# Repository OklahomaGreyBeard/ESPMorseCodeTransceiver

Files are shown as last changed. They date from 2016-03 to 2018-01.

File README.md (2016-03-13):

# ESPMorseCodeTransceiver
A web enabled internet of things morse code sending key with a receiving speaker using the ESP8266.

See a video about this project here:

<a href="http://www.youtube.com/watch?feature=player_embedded&v=fGk9IvxCnt0
" target="_blank">ESP Morse Code Transceiver Video</a>

I used a J-38 WW2 era telegraph key, which can be purchased rather inexpensively on ebay, and 3d printed a case for the bottom for an ESP8266.  I implemented a websocket interface, web server, and morse code decoder, and encoder / sounder.

The original idea for this project was to simply make an IoT button, but things evolved when the idea for dynamic command structures via Morse code came about. With a bit of code extension, this system can easily be made into an internet of things button for home automation, not unlike the amazon 'dash' button, but with the ability to key in dynamic data.  One example would be outputting a REST or MQTT command such as "L50" to a system like OpenHAB, to turn a light on to a 50% dimmer setting.

It can work as a training device, or with a bit of work, send commands to home automation systems, twitter, etc.

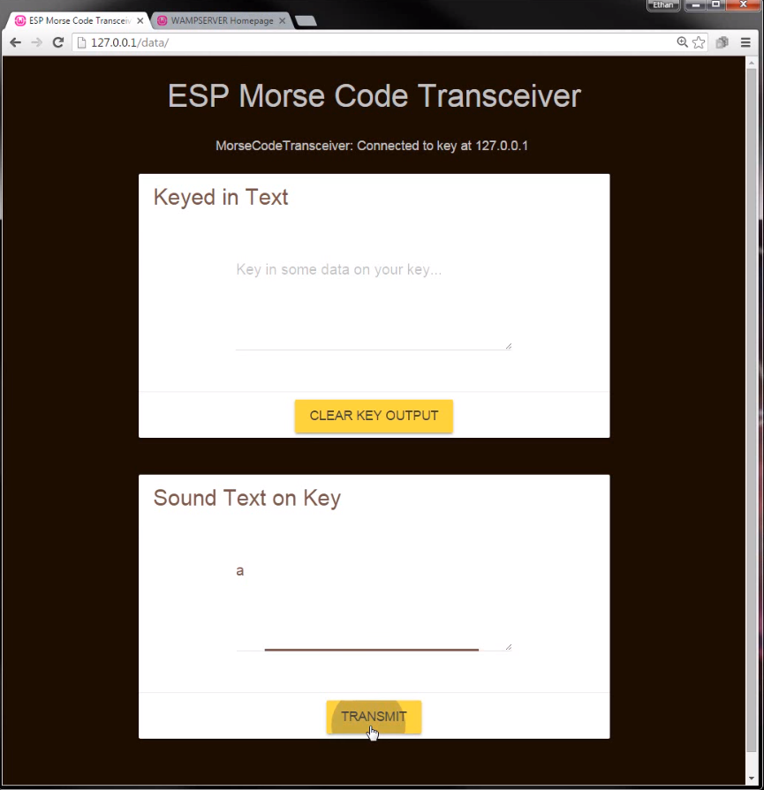
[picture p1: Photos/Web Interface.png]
WebUI

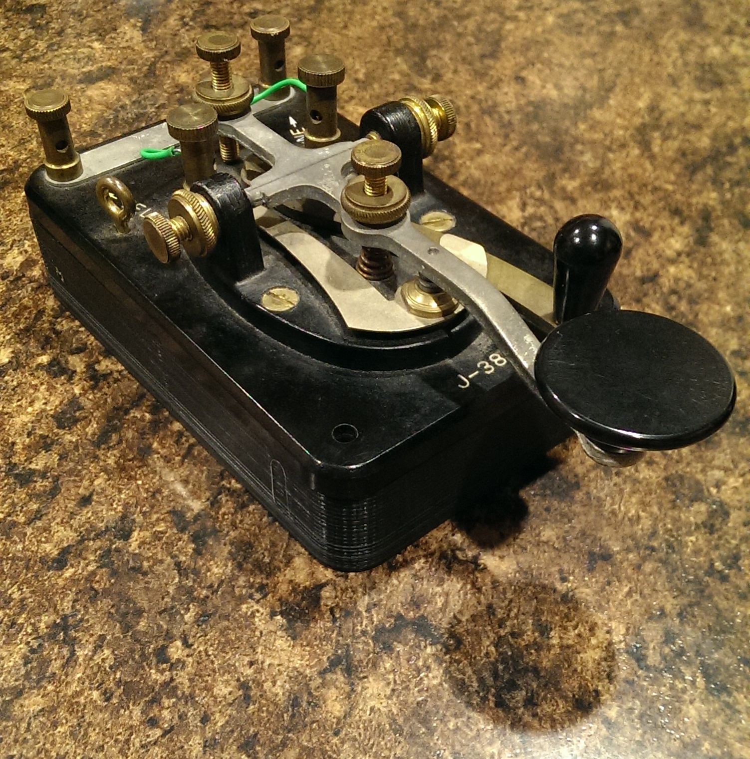
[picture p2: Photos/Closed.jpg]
Closed

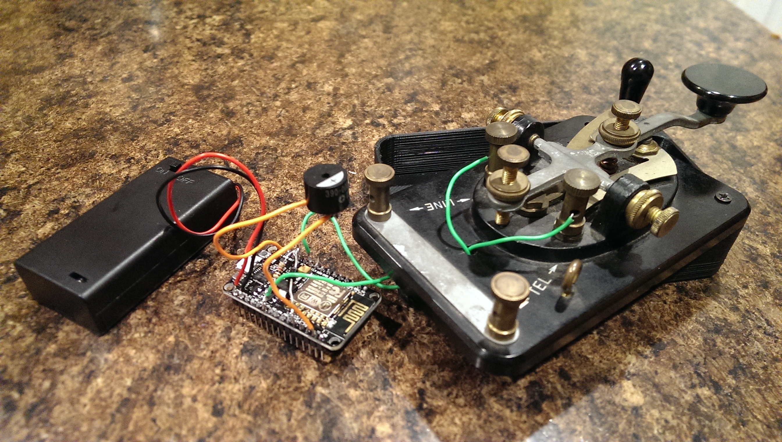
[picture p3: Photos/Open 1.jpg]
Open


Setup Instructions:

Install arduino
get esp arduino with board manager from github link
get arduinoWebSockets-master library
get/install ESP8266fs for the arduino ide.  This lets you send the web content to the eeprom.
Install wifimanager library by tzapu from library manager in arduino ide.
Be sure to restart the arduino IDE

esp will start and bring up an AP, connect to it with password "password"

go to http://esp/, or 192.168.4.1.

Configure wifi.

http://<your esp ip/

To use the key, you'll first need to set the base timing.  Once you hear the "connected" sound, hold the key down for the lenth of a 'dot'.  That will become your base timing, as well as the transmit timing.

You can use the web interface to send ascii text to the receiver, or optionally: http://<esp ip/write?val=SOS to have the ESP sound out or "receive" data.

Here is the electrical schematic you'll need to wire.  It holds the EN / CH_PD pin down when the key is closed so little or no power is used.  Open the key to power up!

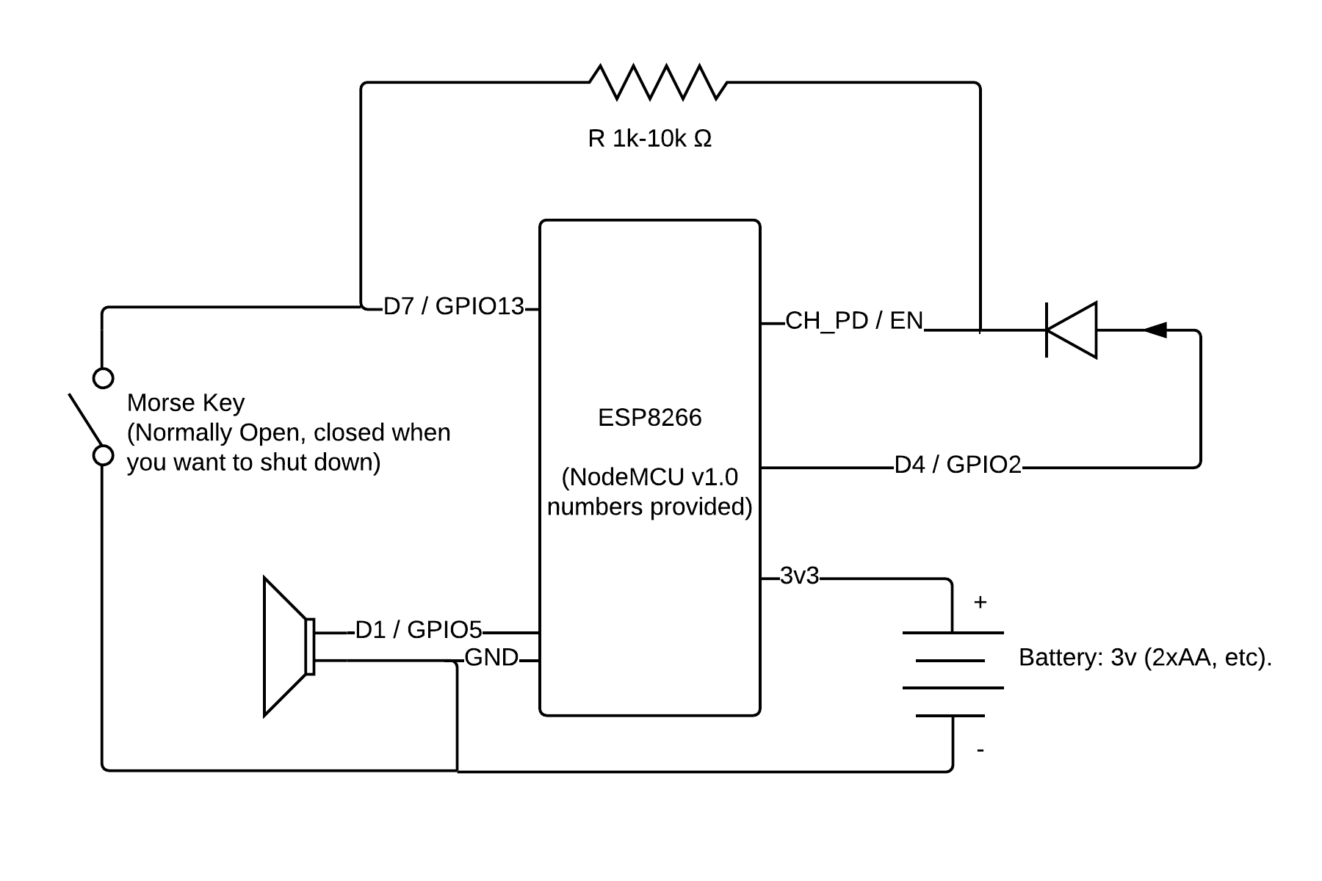
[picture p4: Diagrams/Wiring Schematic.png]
Schematic


Pull requests are welcome, there are lots of "TODO" items to make eveything work better, and some are features I may or may not get around to adding.

If you plan to modify or contribute to the key input sequence, this diagram might be helpful:

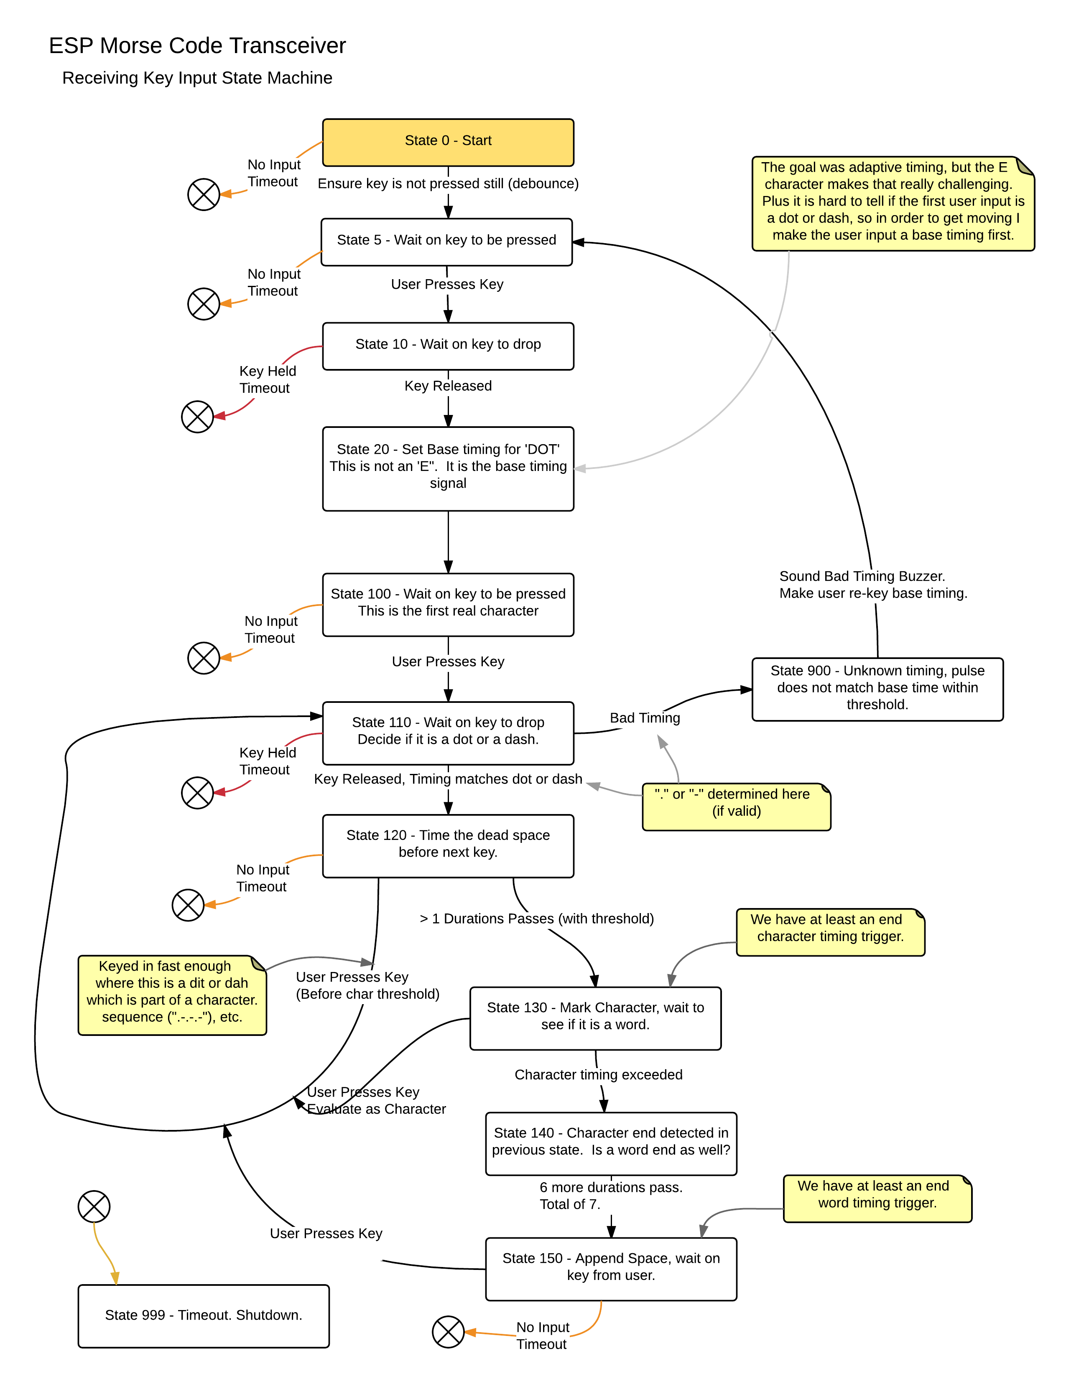
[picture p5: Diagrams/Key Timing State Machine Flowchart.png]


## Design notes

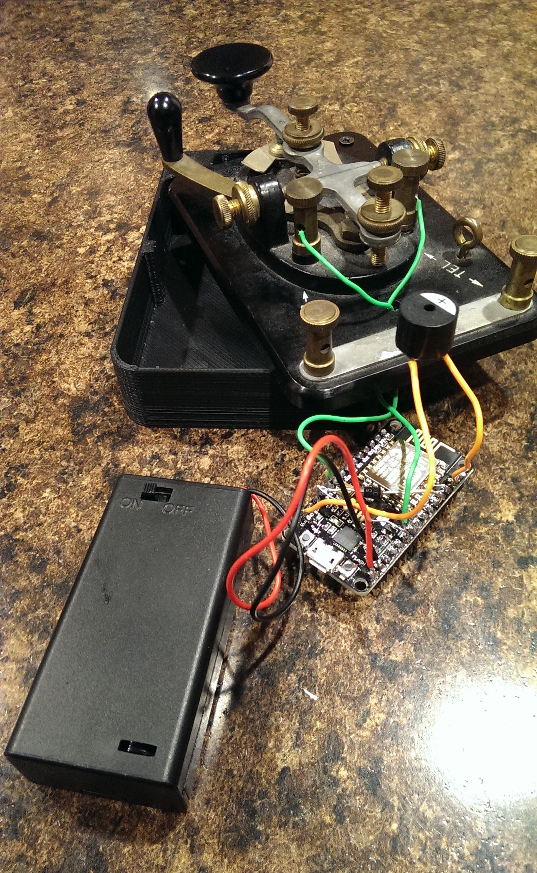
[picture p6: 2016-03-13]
Photos/Open 2.jpg

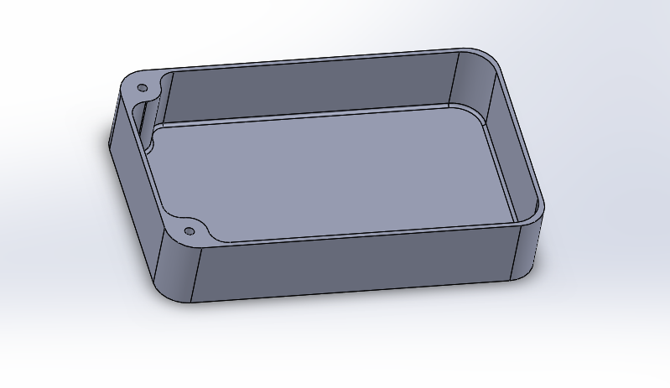
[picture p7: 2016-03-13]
CAD/Case Bottom Screenshot J-38 Key.png

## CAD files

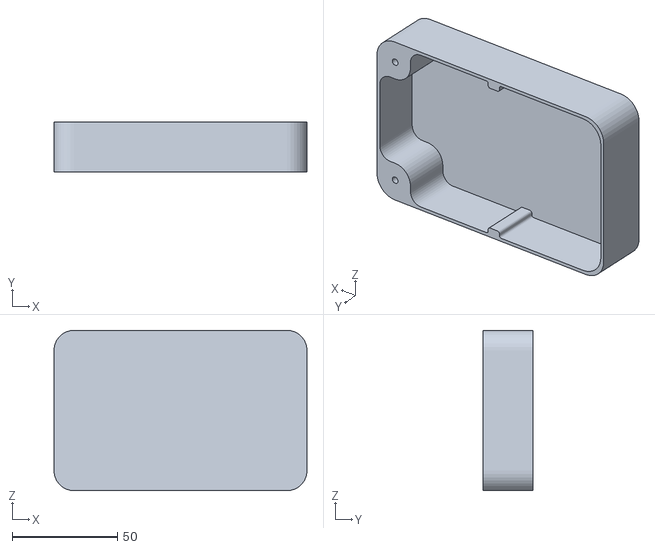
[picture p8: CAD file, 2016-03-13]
CAD/Case Bottom Screenshot J-38 Key.STL
120.4 x 24.0 x 76.3

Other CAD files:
CAD/Case Bottom Screenshot J-38 Key Solidworks 2016.SLDPRT

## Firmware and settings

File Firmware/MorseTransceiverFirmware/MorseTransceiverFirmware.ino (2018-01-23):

#include <WiFiManager.h>


 /*
 * MorseTransceiver.ino
 *
 *  Created on: Mar01 2013
 *
 *  By: evanmj@gmail.com
 *  
 *  Based morse code/timing from: http://morsecode.scphillips.com/morse2.html
 *  
 *  TODO: Consider beeping while button down? Mayb as an option.
 *  TODO: Not all supported characters handled properly.  Need added to array.
 *  TODO: Prosigns not supported, SOS being one of them as 3 chars it no char space.
 *  TODO: full stop (period char) should newline on websocket.
 *  TODO: If any websockets connected, avoid timeout!
 *  TODO: REST output on some signal, maybe full stop, but probably something less used like "!"?
 *  TODO: Handle delete key to clear screen or backspace. "........"
 *  TODO: Different noise if too high or too low
 *  TODO: Shutting lever for a while needs to kill it even when being transmitted to.
 *  
 */

#include <Arduino.h>

#include <ESP8266WiFi.h>
#include <ESP8266WiFiMulti.h>
#include <WebSocketsServer.h>
#include <ESP8266WebServer.h>
#include <ESP8266mDNS.h>
#include <Hash.h>
#include <Timer.h>


#include <FS.h>

#define USE_SERIAL Serial

// Setup automatic magic wifi selection system.
ESP8266WiFiMulti WiFiMulti;

// Instantiate server objects
ESP8266WebServer server(80);
WebSocketsServer webSocket = WebSocketsServer(81);

/* CONSTANTS */


//static unsigned long KEY_DEBOUNCE_TIME = 6000; // Units: microseconds. Per: http://www.qsl.net/sv8gxc/blog/100905-03.jpg, 1.2 sec per pulse = 1 WPM, 140WPM is super fast, so .006 seconds (6ms) seems legit for debounce (max 200WPM detectable).  
static unsigned long KEY_DEBOUNCE_TIME = 9000; // Units: microseconds. Make a bit softer.  A capacitor will probably help but there is not one within reach.
static float PULSE_DURATION_THRESHOLD = 0.50; // How close does a duration need to be to a previous duration to match that it is a dot or a dash? (% of time).  Higher is easier on the user, but don't go over 50% of you'll lose the ability to distingusih a dot from a dash!
static float DASH_TO_DOT_TIME_RATIO = 3.0; // This is standard, the time a dot is is one time unit, one dash is 3 time units.
static float TIME_BETWEEN_CHARS = 3.0; // This is standard, three non transmitting time constant between characters,
static float TIME_BETWEEN_WORDS = 7.0; // This is standard, the non transmitting time constant between words, typically 7 dot time constants.
static float DEFAULT_BASE_TIME_MICROS = 100000; // Default Base time, receive sounds at this rate until user keys in a new rate.  Number in microseconds per 'dot' time constant.
static unsigned long RECIEVE_SOUND_FREQ = 1000; // Frequency to play incoming data (Hz) 600-1000Hz typical.
static unsigned long NO_INPUT_TIMEOUT = 60000; // 30 seconds to shut down with no input.
static unsigned long KEY_HELD_TIMEOUT = 5000; // 5 seconds to shut down with key held down.


/* LOCAL VARIABLES */

int iState; // State machine state.
int iLastState; // Previous State machine state.
bool bFirstScanInState; // True for one time through when state is first entered.
bool bCharEndTimerElapsed; // True when CharEnd timer expires, user lets off for 3 key durations.

bool bWD_Done;  // Watchdog timer elapsed.

// Time keeping of input key pushes
volatile unsigned long iKeyStateChangedTime = 0; // Value in microseconds.
volatile unsigned long iKeyInStateForDeltaTime = 0;  // How long was the key in state for?
bool bKeyPressed; // We will need to keep track of if the button is pressed or not, and the duration.  False = not pressed, True = pressed.
unsigned long iBaseKeyDuration = DEFAULT_BASE_TIME_MICROS; // Scratch space for storing previous key lengths.  Start with a number in case we sound out a message before user inputs one to set base rate.


// Declare timer
Timer Watchdog_tmr;
int Watchdog_tmrEventID;

Timer CharEndTimer;
int CharEnd_tmrEventID;




//In progress character
String DotDashString;  //  dot-dash character array.
char DecodedChar; // ascii char decoded from user input

//In progress String, pre send to REST, etc.  Terminated (eventually) by full stop (period).
String CurrentDecodedString;
char NewestDecodedCharacter;

const char latinAlphabet[30] = { 'A', 'B', 'C', 'D', 'E', 'F', 'G', 'H', 'I', 'J', 'K', 'L', 'M', 'N', 'O', 'P', 'Q', 'R', 'S', 'T', 'U', 'V', 'W', 'X', 'Y', 'Z', '.', ',' };
// NOTE: Does not handle lower case.  Convert all inputs to upper before comparing.

const String morseAlphabet[30] = { ".-", "-...", "-.-.", "-..", ".", "..-.", "--.", "....", "..", ".---", "-.-", ".-..", "--", "-.", "---", ".--.", "--.-", ".-.", "...", "-", "..-", "...-", ".--", "-..-", "-.--", "--..", ".-.-.-", "--..--" };

String DecodedStringToTransmit;  // String in morse to send to the speaker.
String PayloadAsString;  // Uppercase String in morse to send to the speaker.

/* END LOCAL VARIABLES */


void morse_to_sound(String inputstring, unsigned freq);
void string_to_morse(String &dest, String inputstring); 

/* WEB FUNCTIONS */

// This function runs when a new websocket event arrives.
void webSocketEvent(uint8_t num, WStype_t type, uint8_t * payload, size_t length) {

    switch(type) {
        case WStype_DISCONNECTED:
            USE_SERIAL.printf("[%u] Disconnected!\n", num);
            break;
        case WStype_CONNECTED: {
            IPAddress ip = webSocket.remoteIP(num);
            USE_SERIAL.printf("[%u] Connected from %d.%d.%d.%d url: %s\n", num, ip[0], ip[1], ip[2], ip[3], payload);

            // send message to client
            webSocket.sendTXT(num, "Connected! This message is from the ESP");
        }
            break;
        case WStype_TEXT:
        
            USE_SERIAL.printf("[%u] get Text: %s\n", num, payload);
            Serial.println();

            // Javascript prepends a 't' to let us know to transmit.  Maybe S = settings, etc.  
            if(payload[0] == 't') {
                // we got command data that we need to transmit.

                PayloadAsString = (const char *) &payload[1];

                // Make uppercase so string_to_morse likes it.
                PayloadAsString.toUpperCase();

                // Trim leading character, we are done with it ("t" in this case)
                //PayloadAsString.substring(1);

                // Null this so we don't concat like string_to_morse does.
                DecodedStringToTransmit = "";
                
                // Convert it to dots and dashes.
                string_to_morse(DecodedStringToTransmit,PayloadAsString);
                
                
                Serial.println("Sounding morse payload: " + DecodedStringToTransmit);

                morse_to_sound(DecodedStringToTransmit, RECIEVE_SOUND_FREQ);

            }


            break;

         case WStype_BIN:
            USE_SERIAL.printf("[%u] get binary length: %u\n", num, length);
            
            break;
    }
    

}

// Unused, needs implemented instead of other lame 404
/*void handleNotFound(){
  digitalWrite(led, 1);
  String message = "File Not Found\n\n";
  message += "URI: ";
  message += server.uri();
  message += "\nMethod: ";
  message += (server.method() == HTTP_GET)?"GET":"POST";
  message += "\nArguments: ";
  message += server.args();
  message += "\n";
  for (uint8_t i=0; i<server.args(); i++){
    message += " " + server.argName(i) + ": " + server.arg(i) + "\n";
  }
  server.send(404, "text/plain", message);
  digitalWrite(led, 0);
}*/

String getContentType(String filename){
  if(server.hasArg("download")) return "application/octet-stream";
  else if(filename.endsWith(".htm")) return "text/html";
  else if(filename.endsWith(".html")) return "text/html";
  else if(filename.endsWith(".css")) return "text/css";
  else if(filename.endsWith(".js")) return "application/javascript";
  else if(filename.endsWith(".png")) return "image/png";
  else if(filename.endsWith(".gif")) return "image/gif";
  else if(filename.endsWith(".jpg")) return "image/jpeg";
  else if(filename.endsWith(".ico")) return "image/x-icon";
  else if(filename.endsWith(".xml")) return "text/xml";
  else if(filename.endsWith(".pdf")) return "application/x-pdf";
  else if(filename.endsWith(".zip")) return "application/x-zip";
  else if(filename.endsWith(".gz")) return "application/x-gzip";
  return "text/plain";
}

bool handleFileRead(String path){
  USE_SERIAL.println("handleFileRead: " + path);
  if(path.endsWith("/")) path += "index.html";
  String contentType = getContentType(path);
  String pathWithGz = path + ".gz";
  if(SPIFFS.exists(pathWithGz) || SPIFFS.exists(path)){
    if(SPIFFS.exists(pathWithGz))
      path += ".gz";
    File file = SPIFFS.open(path, "r");
    size_t sent = server.streamFile(file, contentType);
    file.close();
    return true;
  }
  else
  {
    USE_SERIAL.println("File does not exist: " + path);
  }
  return false;
}



/* MORSE FUNCTIONS */

// Let the compiler know about our interrupt functions or it will complain about one calling before the other exists, etc.
extern void risingedge();
extern void fallingedge();


// Convert letters in a string to a string of morse code dots and dashes.
void string_to_morse(String &dest, String inputstring) 
{

  for (unsigned i = 0; i<inputstring.length(); ++i)
    {
        for (int counter = 0; counter < 30; counter++)
        {
                if (inputstring.charAt(i) == latinAlphabet[counter])
                {
                    dest += morseAlphabet[counter];
                    //break;  <= force first char, let user decide instead.
                    
                }
        }
    }

}

// Convert a character to a string of morse code dots and dashes.
void char_to_morse(String &dest, char inputstring) 
{
  
      for (int counter = 0; counter < 30; counter++)
        {
                if (inputstring == latinAlphabet[counter])
                {
                    dest = morseAlphabet[counter];
                                       
                }
        }

}

// Convert morese to an ascii character
char morse_to_char(String inputstring) 
{
    for (unsigned i = 0; i<inputstring.length(); ++i)
    {

      for (int counter = 0; counter < 30; counter++)
        {
                if (inputstring == morseAlphabet[counter])
                {
                    return latinAlphabet[counter];
                                       
                }
        }
      
    }


    
      

}

// Dwell one 'between character' length of time.
void dwell_char()
{
  delay(2*iBaseKeyDuration/1000);  // Delay one 'next character', or 'between characters' pause.  This is typically 3 durations, but morse_to_sound appends one duration already.
}

// Sound out a dot-dash string of morse code, i.e. "..---"
void morse_to_sound(String inputstring, unsigned freq)
{

  for (unsigned i = 0; i<inputstring.length(); ++i)
    {

      if (inputstring.charAt(i) == '.') 
      {
        // Sound DOT  
          analogWriteFreq(RECIEVE_SOUND_FREQ);
          analogWrite(D1, 512);
          delay(iBaseKeyDuration/1000);            // on time.  1 duration.
          analogWrite(D1, 0);
          delay(iBaseKeyDuration/1000);            // gap before next pulse. 1 duration.
      }
      else if (inputstring.charAt(i) == '-') 
      {
        // Sound DASH
          analogWriteFreq(RECIEVE_SOUND_FREQ);
          analogWrite(D1, 512);
          delay(3*iBaseKeyDuration/1000);            // on time.  3 durations.
          analogWrite(D1, 0);
          delay(iBaseKeyDuration/1000);            // gap before next pulse. 1 durations.
      }
      else if (inputstring.charAt(i) == ' ') 
      {
        // Sound SPACE (next word)          
          delay(7*iBaseKeyDuration/1000);            // gap before next pulse. 7 durations.
      }     
    }
  
}

/* INTERRUPT KEY IN FUNCTIONS */

void risingedge() {
    // Start with debounce
    if ((micros() - iKeyStateChangedTime) > KEY_DEBOUNCE_TIME)
    {
      iKeyInStateForDeltaTime = micros() - iKeyStateChangedTime;  // NOTE: BUG HERE.  When this rolls over
      iKeyStateChangedTime = micros();  // Mark for next time.
      //Serial.printf("Rising Edge, Key Pressed Going to 0, was on for %d micros", iKeyInStateForDeltaTime);
      //Serial.println();
      attachInterrupt(digitalPinToInterrupt(D7), fallingedge, FALLING);  // Now set to interrupt on falling edge.
      bKeyPressed = 0;
    }
    else
    {
      //Serial.println("Nulled some rising fuzz");
    }

}
 
void fallingedge() {

    // Start with debounce
    if ((micros() - iKeyStateChangedTime) > KEY_DEBOUNCE_TIME)
    {    
      iKeyInStateForDeltaTime = micros() - iKeyStateChangedTime;  // NOTE: BUG HERE.  When this rolls over
      iKeyStateChangedTime = micros();  // Mark for next time.
      //Serial.printf("Falling Edge, Key Pressed Going to 1, was on for %d micros", iKeyInStateForDeltaTime);
      //Serial.println();
      attachInterrupt(digitalPinToInterrupt(D7), risingedge, RISING);  // Now set to interrupt on rising edge.
      bKeyPressed = 1;
      iKeyStateChangedTime = micros();
    }
        else
    {
      //Serial.println("Nulled some falling fuzz");
    }
 
}

void WDTimerElapsed()
{
  Serial.println("WDTimerElapsed() Running.");
  bWD_Done = 1;
}
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
void loop() {

    webSocket.loop();
    server.handleClient();

    // Make sure TCP and stuff has time to run.
    yield();

    

    // Run state machine.
    switch(iState) {

      case 0:  // Initial - Wait on user to press single key to initiate base timing.
     
        // Runs one time on state entry.
        if (bFirstScanInState == 1) 
        {
          DotDashString = ""; // Null dot dash string.
          // Start watchdog timer.
          Watchdog_tmrEventID = Watchdog_tmr.after(KEY_HELD_TIMEOUT, WDTimerElapsed);  // Set Timer
      
        }
      
        // Start
        if (bKeyPressed == 0)
        {
          iState = 5;  
        }
        else
        {
          Serial.println("Key pressed on start, waiting on it to drop before starting.");
          delay(10);
        }

        // Watch for timeout
        if (bWD_Done == 1)
        {
          Serial.println("WD in State" + iState);
          iState = 999;  // Shutdown.
        }

          

      case 5:  // Wait on first key press - This sets base timing for a "dot", and is not an 'E' character!
     
        // Runs one time on state entry.
        if (bFirstScanInState == 1) 
        {
          // Start watchdog timer.
          Watchdog_tmrEventID = Watchdog_tmr.after(NO_INPUT_TIMEOUT, WDTimerElapsed);  // Set Timer      
        }
      
        // User pressed key.  Go!
        if (bKeyPressed == 1)
        {
          iState = 10;  
        }
        
        // Watch for timeout.
        if (bWD_Done == 1)
        {
          Serial.println("WD in State" + iState);
          iState = 999;  // Shutdown.
        }

        break;

      case 10:  // Wait on key to drop for timing initialization sequence.  The amount of time held here is what the user wants to be a "dot".
     
        // Runs one time on state entry.
        if (bFirstScanInState == 1) 
        {
          // Start watchdog timer.
          Watchdog_tmrEventID = Watchdog_tmr.after(KEY_HELD_TIMEOUT, WDTimerElapsed);  // Set Timer
        }

        // Key _just_ released. 
        // Key went off.  We have our timing.
        if (bKeyPressed == 0)
        {
          iState = 20;  
        }

        // Watch for timeout
        if (bWD_Done == 1)
        {
          Serial.println("WD in State" + iState);
          iState = 999;  // Shutdown.
        }

        break;

      case 20: // Key went off, we should have our base timing now for "dot".

        // Store our base timing.
        iBaseKeyDuration = iKeyInStateForDeltaTime;
        
        // Here is where we could send info to connected websockets to let them know what our WPM is.
        // Wikipedia has the milliseconds to WPM formula... TODO.

        delay(1000);  // Delay 1 second, then echo back what they set.

        // Sound buzzer letting user know how long we recieved their button push, and letting them know it is time to key in some dater.
        analogWriteFreq(RECIEVE_SOUND_FREQ);
        analogWrite(D1, 512);
        delay(iBaseKeyDuration/1000);            // on time.  1 duration.
        analogWrite(D1, 0);
          

        iState = 100;

        break;

      case 100:  // Timing decided.  Wait on first key press for first actual character from user.
     
        // Runs one time on state entry.
        if (bFirstScanInState == 1) 
        {
          // Start watchdog timer.
          Watchdog_tmrEventID = Watchdog_tmr.after(NO_INPUT_TIMEOUT, WDTimerElapsed);  // Set Timer
        }
      
        // User pressed key.  Go!
        if (bKeyPressed == 1)
        {
          iState = 110;  
        }
        
        // Watch for timeout.
        if (bWD_Done == 1)
        {
          Serial.println("WD in State" + iState);
          iState = 999;  // Shutdown.
        }

        break;


      case 110:  // Wait on key to drop for reciving dot or dash..  The amount of time held here is what determines a dot or dash.
     
        // Runs one time on state entry.
        if (bFirstScanInState == 1) 
        {
          // Start watchdog timer.
          Watchdog_tmrEventID = Watchdog_tmr.after(KEY_HELD_TIMEOUT, WDTimerElapsed);  // Set Timer
        }

        // Key _just_ released. 
        // Key went off.  We have our dot or dash timing from the user.
        if (bKeyPressed == 0)
        {
          // We have a push and release time now, it is time to determine if the user wanted a dot or a dash.

          // See what sort of pulse we are dealing with.  If we are about 3x, we have a dash after a dot.  
          if ( iKeyInStateForDeltaTime < (iBaseKeyDuration * (1 + PULSE_DURATION_THRESHOLD)) && (iKeyInStateForDeltaTime > (iBaseKeyDuration * (1 - PULSE_DURATION_THRESHOLD))) )  // Are we +/- 50% (depending on constant) from valid timing?
            {
              Serial.println("110: .");
              DotDashString += "."; // Concatenate input we just received.
     
              iState = 120;  
            }
          else if(iKeyInStateForDeltaTime < (iBaseKeyDuration * ((1 + PULSE_DURATION_THRESHOLD) * DASH_TO_DOT_TIME_RATIO)) && (iKeyInStateForDeltaTime > (iBaseKeyDuration * ((1 - PULSE_DURATION_THRESHOLD) * DASH_TO_DOT_TIME_RATIO))) ) // Are we 250%-350%?  That would be a dash.
            {
              Serial.println("110: -");
              DotDashString += "-";
             
              iState = 120;  
            }
          else{
            Serial.printf("Bad Timing: iBaseKeyDuration Was: %d and you entered: %d", iBaseKeyDuration, iKeyInStateForDeltaTime);
            Serial.println();
            iState = 900;  // Bad timing... Buzz, then Make user re-key base timing.
          }

         
        }

        // Watch for timeout
        if (bWD_Done == 1)
        {
          Serial.println("WD in State" + iState);
          iState = 999;  // Shutdown.
        }

        break;

      case 120:  // Time the dead space before the next key.  This accounts for character endings.  
                 // Timing is important, as some characters are long and contain other character's dot dash sequences in them.
     
        // Runs one time on state entry.
        if (bFirstScanInState == 1) 
        {
          // Start watchdog timer.
          Watchdog_tmrEventID = Watchdog_tmr.after(NO_INPUT_TIMEOUT, WDTimerElapsed);  // Set Timer

          // Watch for "end of character" signal.  If greater than 1 duration, we know we are ending a character (at least, maybe a word).
          CharEnd_tmrEventID = CharEndTimer.after((iBaseKeyDuration * (1 + PULSE_DURATION_THRESHOLD)) / 1000, CharEndTimerElapsed); // Set timer for 1 durations (plus threshold).
        }
      
        // User pressed key.  Go!
        if (bKeyPressed == 1)
        {
          iState = 110;  // Back to 110, we have another dot or dash as part of this character (because we didn't time out yet).
        }

        // Watch for user to delay long enough to attempt to end the dot-dash string as a character.
        if (bCharEndTimerElapsed == 1) // It has been 3 durations with no push. Character should be over.
        { 
          iState = 130;  // Head to 130 where we will decide if this is a character end or even a word end.
        }
        
        // Watch for timeout.
        if (bWD_Done == 1)
        {
          Serial.println("WD in State" + iState);
          iState = 999;  // Shutdown.
        }

        break;

      case 130:  // Mark Character, wait to see if it is a word.
     
        // Runs one time on state entry.
        if (bFirstScanInState == 1) 
        {
          // Watch for "end of word" signal.  If greater than 3 durations, we know we are ending a character (at least, maybe a word).
          CharEnd_tmrEventID = CharEndTimer.after((iBaseKeyDuration * TIME_BETWEEN_CHARS * (1 + PULSE_DURATION_THRESHOLD)) / 1000, CharEndTimerElapsed); // Set timer for 3 durations (plus threshold).
          
          Serial.println("State 130 Character found was: " + String(morse_to_char(DotDashString)));
          
          // Mark this character!
          CurrentDecodedString += String(morse_to_char(DotDashString)); // Append to current working string, we have not sent it anywhere yet.
          //TODO: Send char to websocket if enabled.

          webSocket.sendTXT(0, "m" + String(morse_to_char(DotDashString))); // The m is for the "morse" command so the webpage knows this is morse char to display.
          
          Serial.println("State 130 Detected Character End after dot dash string: " + DotDashString);
          

          // Here we can also parse the newest string to see if we need to send to REST or if we want to newline, etc.
          // That value is: String(morse_to_char(DotDashString))
                             
          DotDashString = ""; // Null string for next time.
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
